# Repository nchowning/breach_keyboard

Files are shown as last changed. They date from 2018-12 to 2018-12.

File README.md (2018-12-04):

# Breach Split Keyboard

This is a hobby project to create a keyboard that fits my needs. I figured why not share my progress.

## Firmware

On this, I took the lazy way out after finding an online firmware builder - [Keyboard Firmware Builder](http://kbfirmware.com/). This thing is awesome. You point it at a [keyboard-layout-editor.com](https://www.keyboard-layout-editor.com) layout, tweak the settings, then it spits out a compiled .hex file (or the [qmk](https://qmk.fm) source if you want). In this repo, I'm including the keyboard-layout-editor json file as well as the Keyboard Firmware Builder config json file. You can just upload that config & have Keyboard Firmware Builder deliver a hex file for you. In the future I might include the qmk source in this repo but I won't bother for now.

Since this keyboard uses a pro micro for each half, the firmware flashing process is a little bit different than if you'd used a teensy 2.0. I've added a reset tact switch so that you can easily program it. Just quickly hit the reset button twice & then fire off something like this:

```
avrdude -p atmega32u4 -P /dev/ttyACM0  -c avr109 -U flash:w:breach-left.hex
```

`/dev/ttyACM0` might be different on your machine so keep that in mind.

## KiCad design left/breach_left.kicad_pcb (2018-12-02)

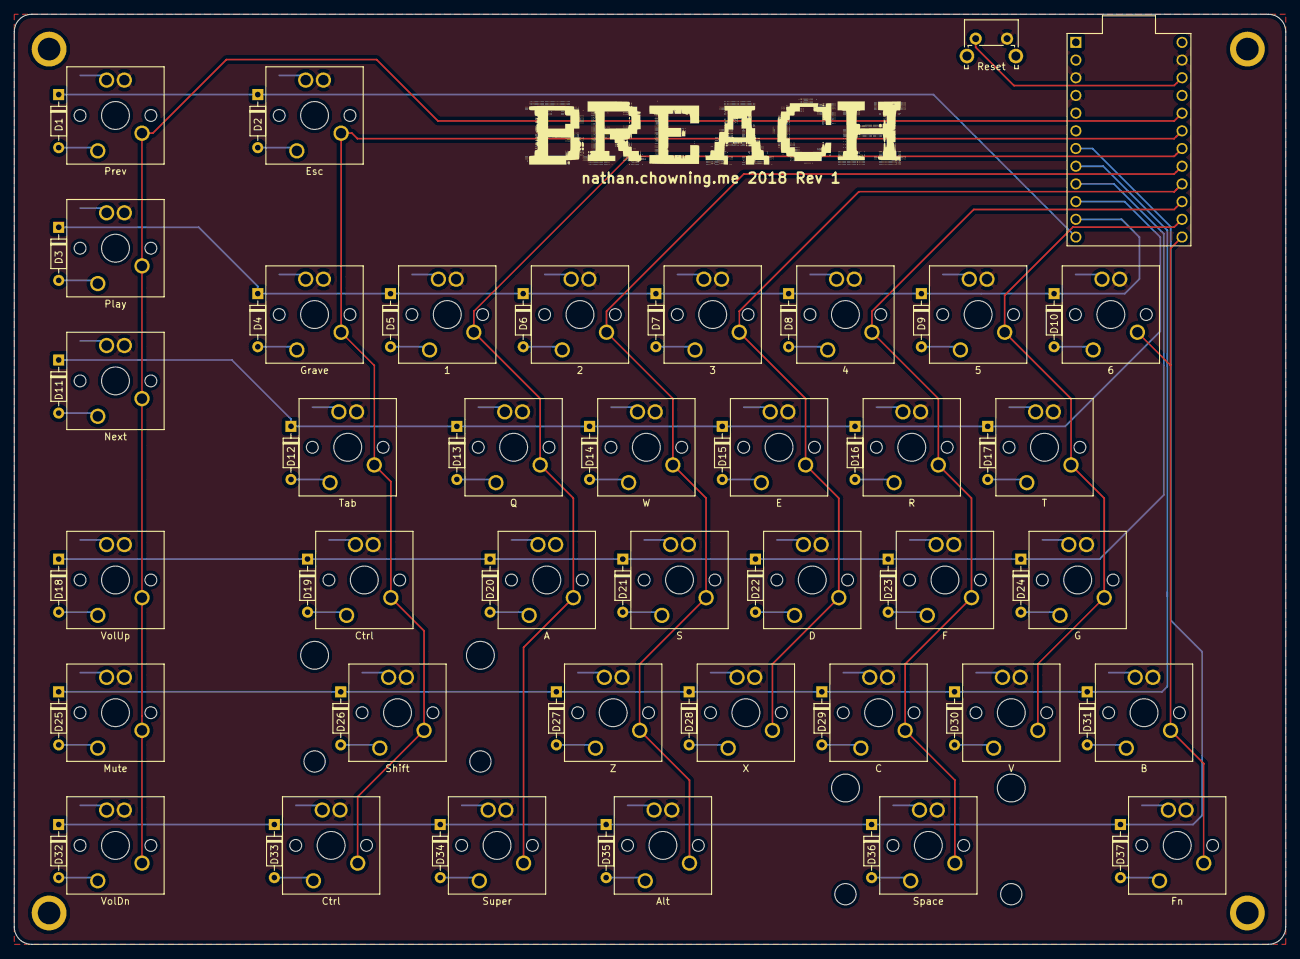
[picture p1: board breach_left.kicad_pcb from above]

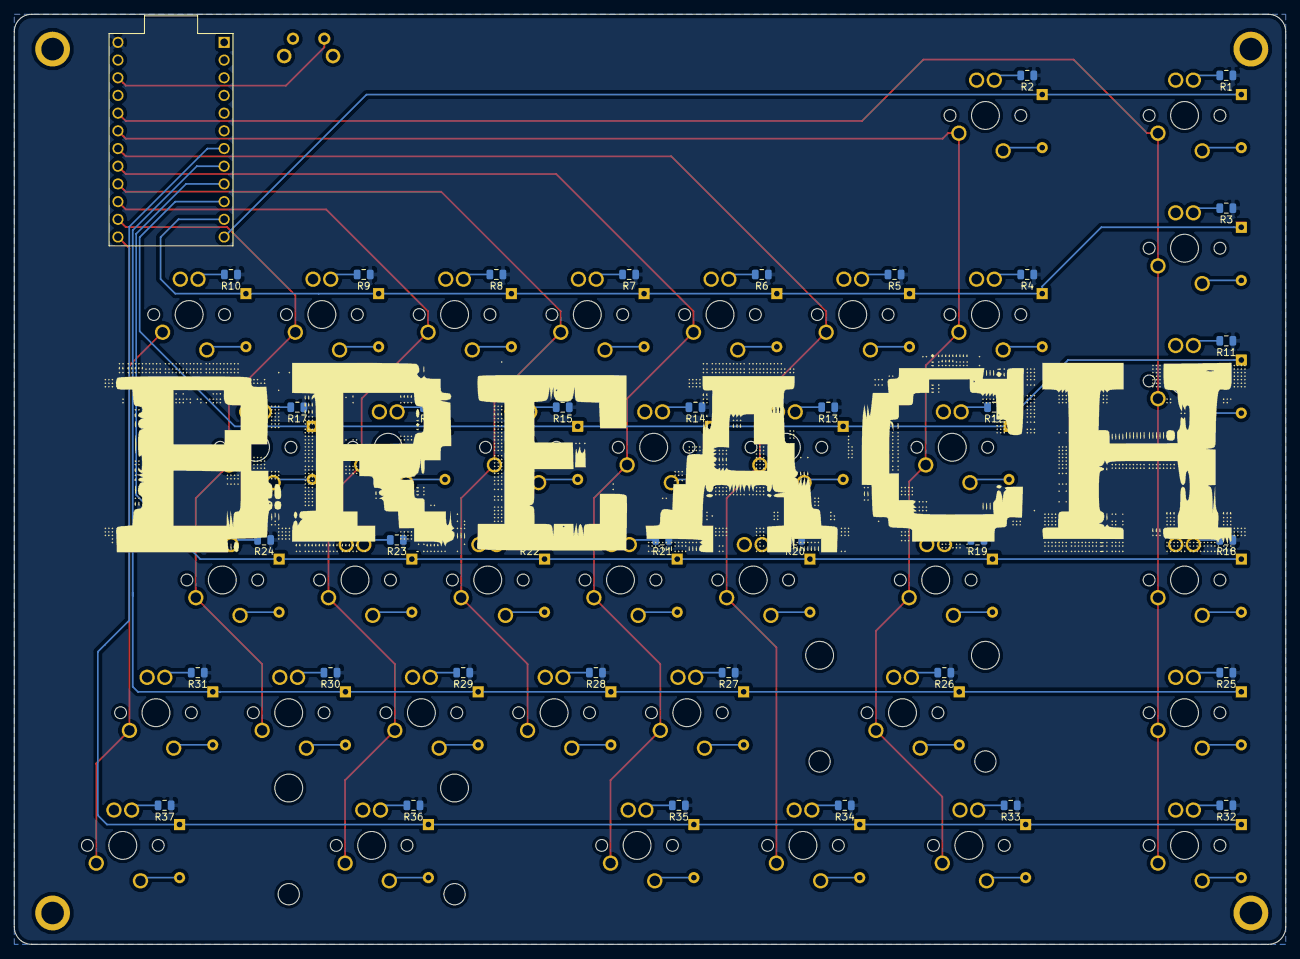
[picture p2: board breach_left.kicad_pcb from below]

Board: 2 copper layers, 182.5 x 133.5 mm, 113 parts (37 on the bottom side), 91 nets.

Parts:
D1, D2, D3, D4, D5, D6, D7, D8, D9, D10, D11, D12, D13, D14, D15, D16, D17, D18, D19, D20, D21, D22, D23, D24, D25, D26, D27, D28, D29, D30, D31, D32, D33, D34, D35, D36, D37: 1N4148; D_DO-35_SOD27_P7.62mm_Horizontal
R1, R2, R3, R4, R5, R6, R7, R8, R9, R10, R11, R12, R13, R14, R15, R16, R17, R18, R19, R20, R21, R22, R23, R24, R25, R26, R27, R28, R29, R30, R31, R32, R33, R34, R35, R36, R37: R_Small_US; R_0805_2012Metric
SW1, SW2, SW3, SW4, SW5, SW6, SW7, SW8, SW9, SW10, SW11, SW12, SW13, SW14, SW15, SW16, SW17, SW18, SW19, SW20, SW21, SW22, SW23, SW24, SW25, SW27, SW28, SW29, SW30, SW31, SW32, SW33, SW34, SW35, SW37: SW_Push_LED; SW_Cherry_MX1A_1.00u_PCB
SW26: SW_Push_LED; SW_Cherry_MX1A_2.25u_PCB
SW36: SW_Push_LED; SW_Cherry_MX1A_2.75u_PCB
SW38: SW_Push; SW_Tactile_SPST_Angled_PTS645Vx39-2LFS
U1: ProMicro

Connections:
5V: R1.1, R2.1, R3.1, R4.1, R5.1, R6.1, R7.1, R8.1, R9.1, R10.1, R11.1, R12.1, R13.1, R14.1, R15.1, R16.1, R17.1, R18.1, R19.1, R20.1, R21.1, R22.1, R23.1, R24.1, R25.1, R26.1, R27.1, R28.1, R29.1, R30.1, R31.1, R32.1, R33.1, R34.1, R35.1, R36.1, R37.1, U1.24
COL1: SW1.2, SW3.2, SW11.2, SW18.2, SW25.2, SW32.2, U1.20
COL2: SW2.2, SW4.2, SW12.2, SW19.2, SW26.2, SW33.2, U1.19
COL3: SW5.2, SW13.2, SW20.2, SW34.2, U1.18
COL4: SW6.2, SW14.2, SW21.2, SW27.2, SW35.2, U1.17
COL5: SW7.2, SW15.2, SW22.2, SW28.2, U1.16
COL6: SW8.2, SW16.2, SW23.2, SW29.2, SW36.2, U1.15
COL7: SW9.2, SW17.2, SW24.2, SW30.2, U1.14
COL8: SW10.2, SW31.2, SW37.2, U1.13
GND: SW1.3, SW2.3, SW3.3, SW4.3, SW5.3, SW6.3, SW7.3, SW8.3, SW9.3, SW10.3, SW11.3, SW12.3, SW13.3, SW14.3, SW15.3, SW16.3, SW17.3, SW18.3, SW19.3, SW21.3, SW22.3, SW23.3, SW24.3, SW25.3, SW26.3, SW27.3, SW28.3, SW29.3, SW30.3, SW31.3, SW32.3, SW33.3, SW34.3, SW35.3, SW36.3, SW37.3, SW38.2, U1.3, U1.4, U1.23
unnamed: D1.2, SW1.1
unnamed: D2.2, SW2.1
unnamed: D3.2, SW3.1
unnamed: D4.2, SW4.1
unnamed: D5.2, SW5.1
unnamed: D6.2, SW6.1
unnamed: D7.2, SW7.1
unnamed: D8.2, SW8.1
unnamed: D9.2, SW9.1
unnamed: D10.2, SW10.1
unnamed: D11.2, SW11.1
unnamed: D12.2, SW12.1
unnamed: D13.2, SW13.1
unnamed: D14.2, SW14.1
unnamed: D15.2, SW15.1
unnamed: D16.2, SW16.1
unnamed: D17.2, SW17.1
unnamed: D18.2, SW18.1
unnamed: D19.2, SW19.1
unnamed: D20.2, SW20.1
unnamed: D21.2, SW21.1
unnamed: D22.2, SW22.1
unnamed: D23.2, SW23.1
unnamed: D24.2, SW24.1
unnamed: D25.2, SW25.1
unnamed: D26.2, SW26.1
unnamed: D27.2, SW27.1
unnamed: D28.2, SW28.1
unnamed: D29.2, SW29.1
unnamed: D30.2, SW30.1
unnamed: D31.2, SW31.1
unnamed: D32.2, SW32.1
unnamed: D33.2, SW33.1
unnamed: D34.2, SW34.1
unnamed: D35.2, SW35.1
unnamed: D36.2, SW36.1
unnamed: D37.2, SW37.1
unnamed: R1.2, SW1.4
unnamed: R2.2, SW2.4
unnamed: R3.2, SW3.4
unnamed: R4.2, SW4.4
unnamed: R5.2, SW5.4
unnamed: R6.2, SW6.4
unnamed: R7.2, SW7.4
unnamed: R8.2, SW8.4
unnamed: R9.2, SW9.4
unnamed: R10.2, SW10.4
unnamed: R11.2, SW11.4
unnamed: R12.2, SW12.4
unnamed: R13.2, SW13.4
unnamed: R14.2, SW14.4
unnamed: R15.2, SW15.4
unnamed: R16.2, SW16.4
unnamed: R17.2, SW17.4
unnamed: R18.2, SW18.4
unnamed: R19.2, SW19.4
unnamed: R20.2, SW20.4
unnamed: R21.2, SW21.4
unnamed: R22.2, SW22.4
unnamed: R23.2, SW23.4
unnamed: R24.2, SW24.4
unnamed: R25.2, SW25.4
unnamed: R26.2, SW26.4
unnamed: R27.2, SW27.4
unnamed: R28.2, SW28.4
unnamed: R29.2, SW29.4
unnamed: R30.2, SW30.4
unnamed: R31.2, SW31.4
unnamed: R32.2, SW32.4
unnamed: R33.2, SW33.4
unnamed: R34.2, SW34.4
unnamed: R35.2, SW35.4
unnamed: R36.2, SW36.4
unnamed: R37.2, SW37.4
ROW1: D1.1, D2.1, U1.12
ROW2: D3.1, D4.1, D5.1, D6.1, D7.1, D8.1, D9.1, D10.1, U1.11
ROW3: D11.1, D12.1, D13.1, D14.1, D15.1, D16.1, D17.1, U1.10
ROW4: D18.1, D19.1, D20.1, D21.1, D22.1, D23.1, D24.1, U1.9
ROW5: D25.1, D26.1, D27.1, D28.1, D29.1, D30.1, D31.1, U1.8
ROW6: D32.1, D33.1, D34.1, D35.1, D36.1, D37.1, U1.7
RST: SW38.1, U1.22

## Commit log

2018-11-14 Renamed the project & pretty much finished the left side
    [breach_keyboard.sch, breach_left.kicad_pcb, split_keyboard.kicad_pcb]
2018-12-02 Lots of new changes here. Left side is usable
    [breach_keyboard.sch, breach_left.kicad_pcb, breach_left.sch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]
